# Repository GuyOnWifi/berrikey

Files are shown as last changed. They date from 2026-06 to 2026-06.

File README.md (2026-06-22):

<p align="center">
  
</p>

<h1 align="center">BerriKey</h1>

**A strawberry-themed, hardware key backed by a tamper-proof Secure Element. Built on top of the FIDO2 protocol. Simply plug it in to any site or app that supports the protocol and register a secure authenticator**

## Features

- **nRF52840** microcontroller
- **SE050**, EAL 6+ certified, tamper proof secure element storage for key storage and cryptography
- **USB-C and USB-A** connectivity
- **Capacitive touch pad** for user verification
- **Strawberry shaped case**

## Why?

I wanted to make an actually secure, open source hardware key that I could use for my accounts. Current options like [Yubikeys](https://www.yubico.com/products/) were great but not open-sourced, and community projects like [PicoKey](https://www.picokeys.com/) did not use tamper-resistant storages, and relied on a [chip with known vulnerabilites to it's security features](https://www.raspberrypi.com/news/security-through-transparency-rp2350-hacking-challenge-results-are-in/). I wanted to make it uniquely mine, so I made it strawberry themed!

### Threat model

The purpose of the project was to create a secure key to protected online identity (avoiding use of passwords, which can be keylogged, over-the-shoulder'ed, or leaked)

The main goals were to address the following:

- adversaries: should defend against well funded actors with lab equipment and knowledge (not state actors with supreme funding), evil maid attacks (semi-brief physical attacks)
- attack surface: all crypto operations are performed on SE, only USB (no nfc / ble).
- trust boundaries: SE is ultimate crypto trust, with all operations on the chip. firmware is trusted out of necessity

Most importantly, keys should never be cloneable off device, which would lead to compromise of online identity without knowledge. This mitigates the biggest risk of stealing the key, where the user is expected to assume that it is lost forever and immediately revoke the keys.

## Credits

Credit goes to the [Nitrokey Team](https://github.com/Nitrokey/nitrokey-3-firmware) for creating open-source keys, which this firmware is based on. Rather then reinviting a FIDO2 stack, I forked it off the battle-tested Nitrokey3 that has undergone security audits - ensuring its security against my threat model. It has been modified to support both a USB-C and USB-A, add support to custom LEDs, capacitive touch pads and easier support for programming with the nRF52840 chip. GHowever, the hardware is custom, with a unique form factor.

## Design

### Wiring

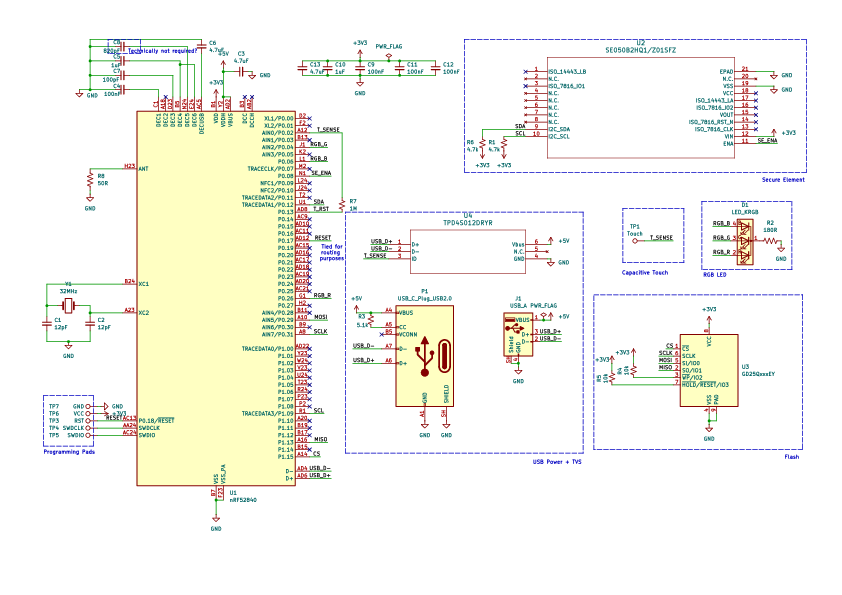
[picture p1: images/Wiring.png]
Wiring


### PCB

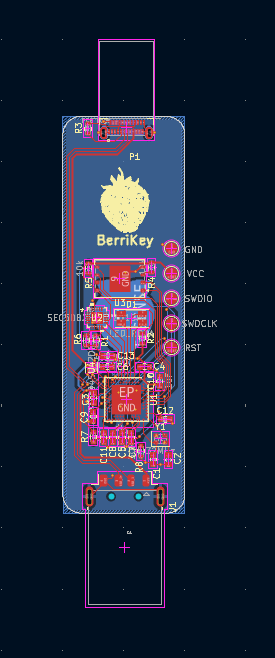
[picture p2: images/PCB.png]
PCB


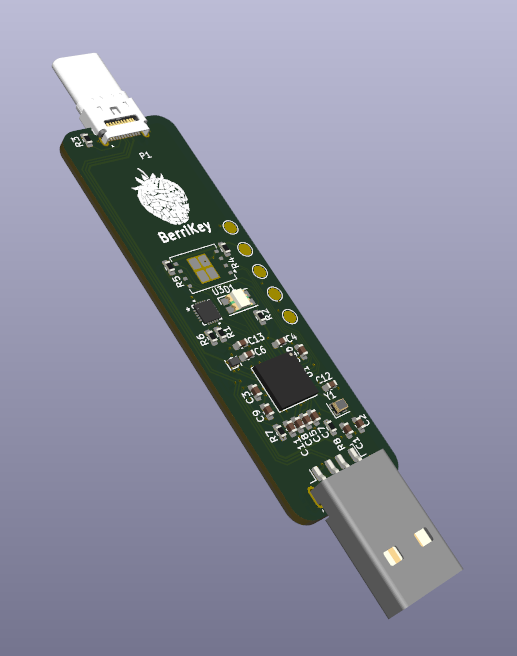
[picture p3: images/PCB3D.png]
PCB-3D


### Case

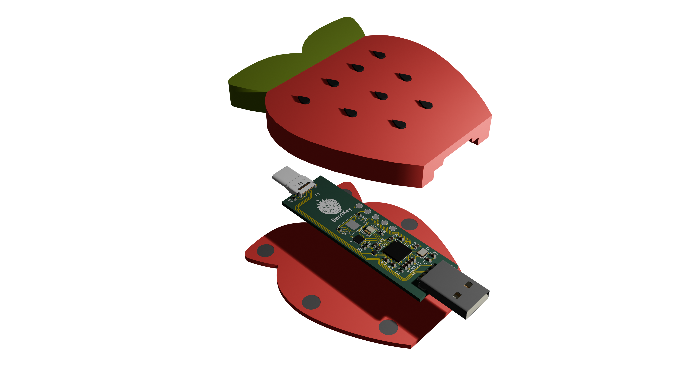
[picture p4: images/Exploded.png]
Exploded view


## Building & Running

5 SWD pads have been exposed on the PCB. Wire them to a CMSIS-DAP debugger (I tested using the RPI debuprobe). Go into `firmware/utils/nrf-builder` and run `make full-deploy`. This will flash the bootloader, provision the keys and certificates, and then flash the firmware.

## Zine

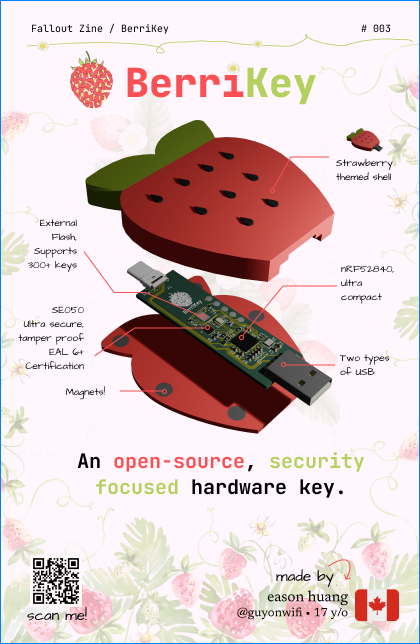
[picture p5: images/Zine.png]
Zine


Check it out [here](./zine.pdf)!

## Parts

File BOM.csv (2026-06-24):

Id | Designator | Footprint | Quantity | Designation | JLCPCB | JLCPCB Link | Price (JLC) | Other Links (unused for JLCPCB assembly, but in case you wanted to build yourself)
1 | C1, C2 | C_0603_1608Metric | 2 | 12pF | Basic Auto Match | N/A | $0.01 | https://www.digikey.ca/en/products/detail/yageo/CC0603JRNPO9BN120/302793
2 | C3, C6, C13 | C_0603_1608Metric | 3 | 4.7uF | Basic Auto Match | N/A | $0.01 | https://www.digikey.ca/en/products/detail/yageo/CC0603KRX5R7BB475/5195193
3 | C4, C9, C11, C12 | C_0603_1608Metric | 4 | 100nF | Basic Auto Match | N/A | $0.01 | https://www.digikey.ca/en/products/detail/yageo/CC0603KRX7R9BB104/2103082
4 | C5, C10 | C_0603_1608Metric | 2 | 1uF | Basic Auto Match | N/A | $0.01 | https://www.digikey.ca/en/products/detail/yageo/CC0603KRX5R9BB105/5195195
5 | C7 | C_0603_1608Metric | 1 | 100pF | Basic Auto Match | N/A | $0.01 | https://www.digikey.ca/en/products/detail/yageo/CC0603JRNPO9BN101/302803
6 | C8 | C_0603_1608Metric | 1 | 820pF | Basic Auto Match | N/A | $0.01 | https://www.digikey.ca/en/products/detail/yageo/CC0603JRNPO9BN821/5195184
7 | D1 | LED_RGB_1210 | 1 | LED_KRGB | FM-B2020RGBA-HG | https://jlcpcb.com/partdetail/110013-FM_B2020RGBAHG/C108793 | $0.02 | https://www.lcsc.com/product-detail/C108793.html
8 | J1 | USB_A_Molex_48037-2200_Horizontal | 1 | USB_A | 48037-2200 | https://jlcpcb.com/partdetail/MOLEX-480372200/C2765195 | $1.01 | https://www.digikey.ca/en/products/detail/molex/0480372200/2421361
9 | P1 | GCT_USB4155-03-C_REVA | 1 | USB_C_Plug_USB2.0 | USB4155-03-C | https://jlcpcb.com/partdetail/5847867-USB4155_03C/C5183853 | $2.22 | https://www.digikey.ca/en/products/detail/gct/USB4155-03-C/14305161
10 | R1, R6 | R_0603_1608Metric | 2 | 4.7k | Basic Auto Match | N/A | $0.01 | https://www.digikey.ca/en/products/detail/yageo/RC0603FR-074K7L/727212
11 | R2 | R_0603_1608Metric | 1 | 180R | Basic Auto Match | N/A | $0.01 | https://www.digikey.ca/en/products/detail/yageo/RC0603FR-07180RL/726994
12 | R3 | R_0603_1608Metric | 1 | 5.1k | Basic Auto Match | N/A | $0.01 | https://www.digikey.ca/en/products/detail/yageo/RC0603FR-075K1L/727268
13 | R4, R5 | R_0603_1608Metric | 2 | 10k | Basic Auto Match | N/A | $0.01 | https://www.digikey.ca/en/products/detail/yageo/RC0603FR-0710KL/726880
14 | R7 | R_0603_1608Metric | 1 | 1M | Basic Auto Match | N/A | $0.01 | https://www.digikey.ca/en/products/detail/yageo/RC0603FR-071ML/726844
15 | R8 | R_0603_1608Metric | 1 | 50R | Basic Auto Match | N/A | $0.01 | https://www.digikey.ca/en/products/detail/yageo/RC0603FR-0749R9L/730211
16 | TP1 | Strawberry_Cap_Touch | 1 | Touch | N/A | N/A | N/A | N/A
17 | TP3 | TestPoint_Pad_D2.0mm | 1 | RST | N/A | N/A | N/A | N/A
18 | TP4 | TestPoint_Pad_D2.0mm | 1 | SWDCLK | N/A | N/A | N/A | N/A
19 | TP5 | TestPoint_Pad_D2.0mm | 1 | SWDIO | N/A | N/A | N/A | N/A
20 | TP6 | TestPoint_Pad_D2.0mm | 1 | VCC | N/A | N/A | N/A | N/A
21 | TP7 | TestPoint_Pad_D2.0mm | 1 | GND | N/A | N/A | N/A | N/A
22 | U1 | Nordic_AQFN-73-1EP_7x7mm_P0.5mm | 1 | nRF52840 | NRF52840-QIAA-R | https://jlcpcb.com/partdetail/NordicSemicon-NRF52840_QIAAR/C190794 | $5.73 | https://www.digikey.ca/en/products/detail/nordic-semiconductor-asa/NRF52840-QIAA-R/7725407
23 | U2 | QFN20_SE050_NXP | 1 | SE050B2HQ1/Z01SFZ | SE050C1HQ1/Z01SCZ | https://jlcpcb.com/partdetail/NXPSemicon-SE050C1HQ1Z01SCZ/C2650415 | $6.17 | https://www.digikey.ca/en/products/detail/nxp-usa-inc/SE050C1HQ1-Z01SCZ/10271723
24 | U3 | WSON-8-1EP_8x6mm_P1.27mm_EP3.4x4.3mm | 1 | GD25QxxxEY | GD25Q16CSIGR | https://jlcpcb.com/partdetail/376201-GD25Q16CSIGR/C395505 | $1.09 | https://www.digikey.ca/en/products/detail/gigadevice-semiconductor-hk-limited/GD25Q16CSIGR/9484689
25 | U4 | DRY6 | 1 | TPD4S012DRYR | TPD4S012DRYR | https://jlcpcb.com/partdetail/TexasInstruments-TPD4S012DRYR/C96506 | $0.43 | https://www.digikey.ca/en/products/detail/texas-instruments/TPD4S012DRYR/2037539
26 | Y1 | Crystal_SMD_3225-4Pin_3.2x2.5mm | 1 | 32MHz | Q22FA12800025 | https://jlcpcb.com/partdetail/SeikoEpson-Q22FA12800025/C187794 | $0.23 | https://www.digikey.ca/en/products/detail/txc-corporation/7V-32-000MAAE-T/2626986
27 | Magnets | 6mmx2mm | 12 | N/A | N/A | N/A | $2.20 | https://www.amazon.ca/GOOZADA-Refrigerator-Magnets-Neodymium-Whiteboards/dp/B0F66HG8RN
Total |  |  |  |  |  |  | $19.22

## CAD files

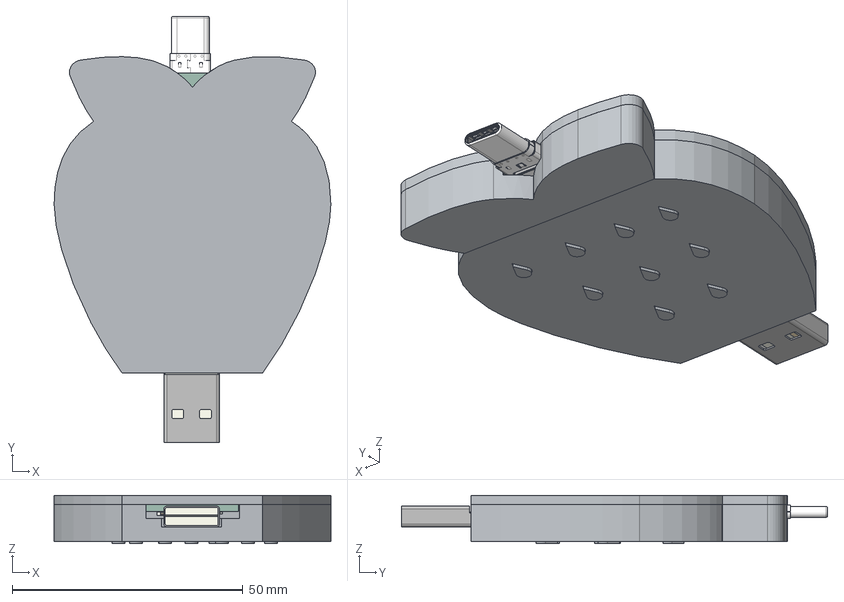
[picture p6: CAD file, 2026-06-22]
3d-models/BerriKey.step
60.0 x 92.3 x 10.5 mm
C_0603_1608Metric
C_0603_1608Metric002
Nordic_AQFN-73-1EP_7x7mm_P0.5mm
R_0603_1608Metric
C_0603_1608Metric004
Ã_Â_Ã_Â¤Ã_Â_Ã_Â«1
Ã_Â_Ã_Â¤Ã_Â_Ã_Â«001
Ã_Â_Ã_Â¤Ã_Â_Ã_Â«002
Ã_Â_Ã_Â¤Ã_Â_Ã_Â«003
Ã_Â_Ã_Â¤Ã_Â_Ã_Â«004
Ã_Â_Ã_Â¤Ã_Â_Ã_Â«005
Ã_Â_Ã_Â¤Ã_Â_Ã_Â«006
Ã_Â_Ã_Â¤Ã_Â_Ã_Â«007
Ã_Â_Ã_Â¤Ã_Â_Ã_Â«008
Ã_Â_Ã_Â¤Ã_Â_Ã_Â«009
Ã_Â_Ã_Â¤Ã_Â_Ã_Â«010
Ã_Â_Ã_Â¤Ã_Â_Ã_Â«011
Ã_Â_Ã_Â¤Ã_Â_Ã_Â«012
Ã_Â_Ã_Â¤Ã_Â_Ã_Â«013
Ã_Â_Ã_Â¤Ã_Â_Ã_Â«014
Ã_Â_Ã_Â¤Ã_Â_Ã_Â«015
Ã_Â_Ã_Â¤Ã_Â_Ã_Â«016
Ã_Â_Ã_Â¤Ã_Â_Ã_Â«017
Ã_Â_Ã_Â¤Ã_Â_Ã_Â«018
Ã_Â_Ã_Â¤Ã_Â_Ã_Â«019
Ã_Â_Ã_Â¤Ã_Â_Ã_Â«020
Ã_Â_Ã_Â¤Ã_Â_Ã_Â«021
Ã_Â_Ã_Â¤Ã_Â_Ã_Â«022
Ã_Â_Ã_Â¤Ã_Â_Ã_Â«023
Ã_Â_Ã_Â¤Ã_Â_Ã_Â«024
Ã_Â_Ã_Â¤Ã_Â_Ã_Â«025
Ã_Â_Ã_Â¤Ã_Â_Ã_Â«026
Ã_Â_Ã_Â¤Ã_Â_Ã_Â«027
Ã_Â_Ã_Â¤Ã_Â_Ã_Â«028
Ã_Â_Ã_Â¤Ã_Â_Ã_Â«029
Ã_Â_Ã_Â¤Ã_Â_Ã_Â«030
Ã_Â_Ã_Â¤Ã_Â_Ã_Â«031
Ã_Â_Ã_Â¤Ã_Â_Ã_Â«032
Ã_Â_Ã_Â¤Ã_Â_Ã_Â«033
Ã_Â_Ã_Â¤Ã_Â_Ã_Â«034
Ã_Â_Ã_Â¤Ã_Â_Ã_Â«035
Ã_Â_Ã_Â¤Ã_Â_Ã_Â«036
Ã_Â_Ã_Â¤Ã_Â_Ã_Â«037
Ã_Â_Ã_Â¤Ã_Â_Ã_Â«038
Ã_Â_Ã_Â¤Ã_Â_Ã_Â«039
Ã_Â_Ã_Â¤Ã_Â_Ã_Â«040
Ã_Â_Ã_Â¤Ã_Â_Ã_Â«041
Ã_Â_Ã_Â¤Ã_Â_Ã_Â«042
Ã_Â_Ã_Â¤Ã_Â_Ã_Â«043
Ã_Â_Ã_Â¤Ã_Â_Ã_Â«044
Ã_Â_Ã_Â¤Ã_Â_Ã_Â«045
Ã_Â_Ã_Â¤Ã_Â_Ã_Â«046
Ã_Â_Ã_Â¤Ã_Â_Ã_Â«047
Ã_Â_Ã_Â¤Ã_Â_Ã_Â«048
Ã_Â_Ã_Â¤Ã_Â_Ã_Â«049
Ã_Â_Ã_Â¤Ã_Â_Ã_Â«050
Ã_Â_Ã_Â¤Ã_Â_Ã_Â«051
Ã_Â_Ã_Â¤Ã_Â_Ã_Â«052
Ã_Â_Ã_Â¤Ã_Â_Ã_Â«053
Ã_Â_Ã_Â¤Ã_Â_Ã_Â«054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

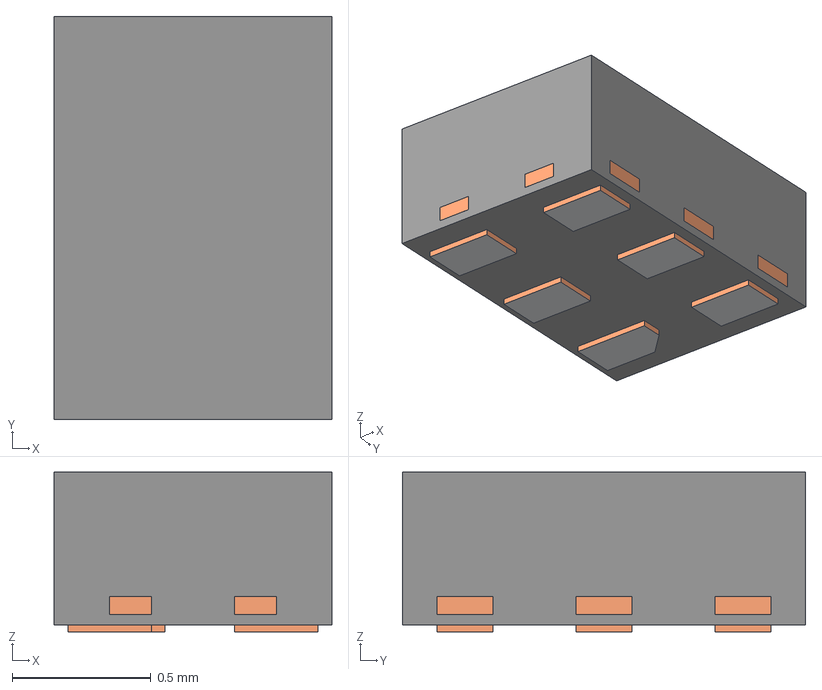
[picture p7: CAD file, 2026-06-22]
kicad/Models/DRY0006A.stp
1.00 x 1.45 x 0.575 mm
BODY-SON
FRAME-DRY0006A
PIN1-ID

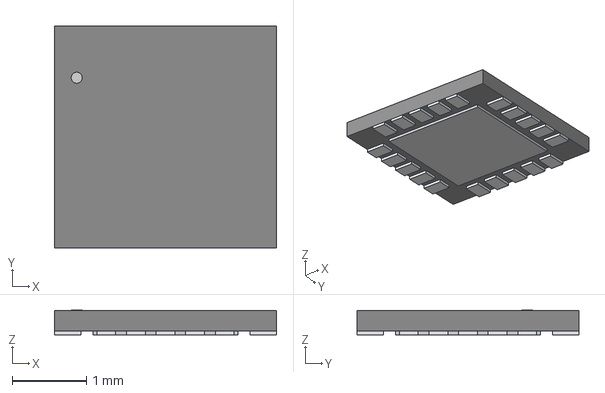
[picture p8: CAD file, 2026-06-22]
kicad/Models/QFN20_SE050_NXP.step
3.00 x 3.00 x 0.333 mm

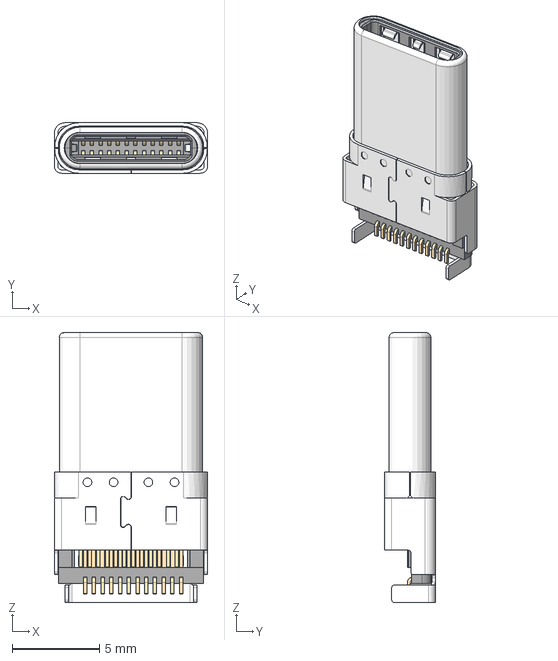
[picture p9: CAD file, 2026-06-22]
kicad/Models/USB4155-03.STEP
8.80 x 2.90 x 15.5 mm
ÊäÈë1 x 7
ÇÐ³ý-ÀÉì2

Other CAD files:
3d-models/BerriKey.FCStd
3d-models/BerriKey.blend

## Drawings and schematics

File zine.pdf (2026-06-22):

# BerriKey

# 003

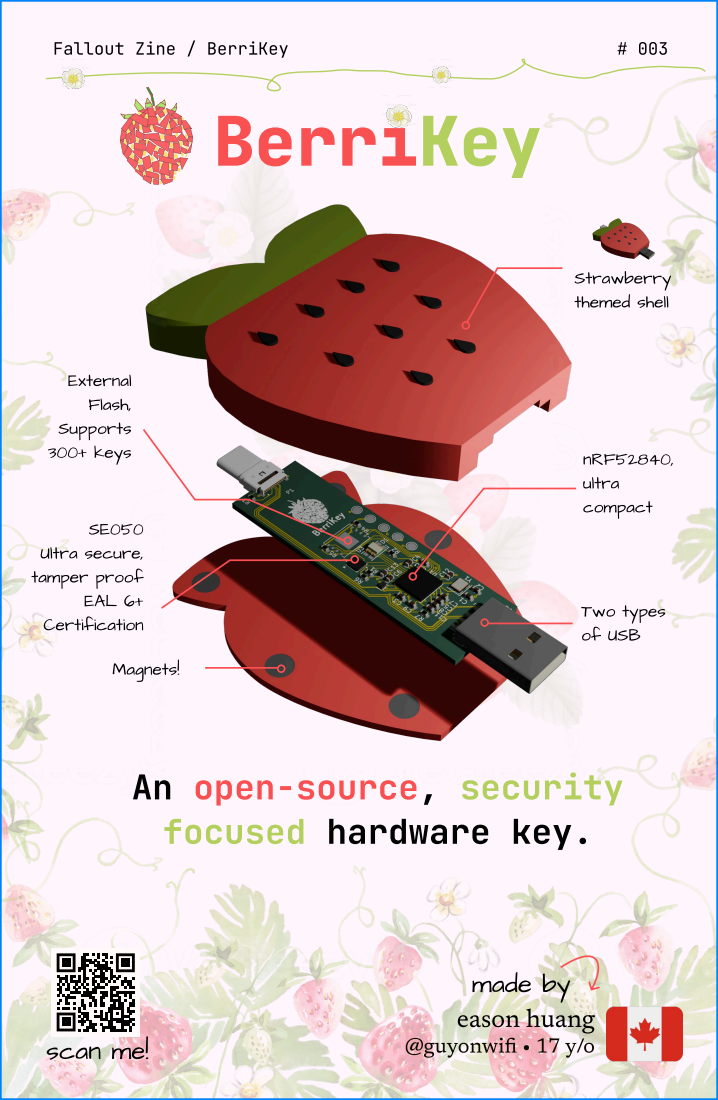
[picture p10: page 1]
Strawberry; themed shell; External; Flash,; Supports; 300+ keys; Ultra secure,; tamper proof; EAL 6+; Certification; Magnets!; nRF52840,; ultra; compact; Two types; of USB; scan me!; made by

Fallout Zine / BerriKey

An open-source, security

focused hardware key.

eason huang @guyonwifi • 17 y/o

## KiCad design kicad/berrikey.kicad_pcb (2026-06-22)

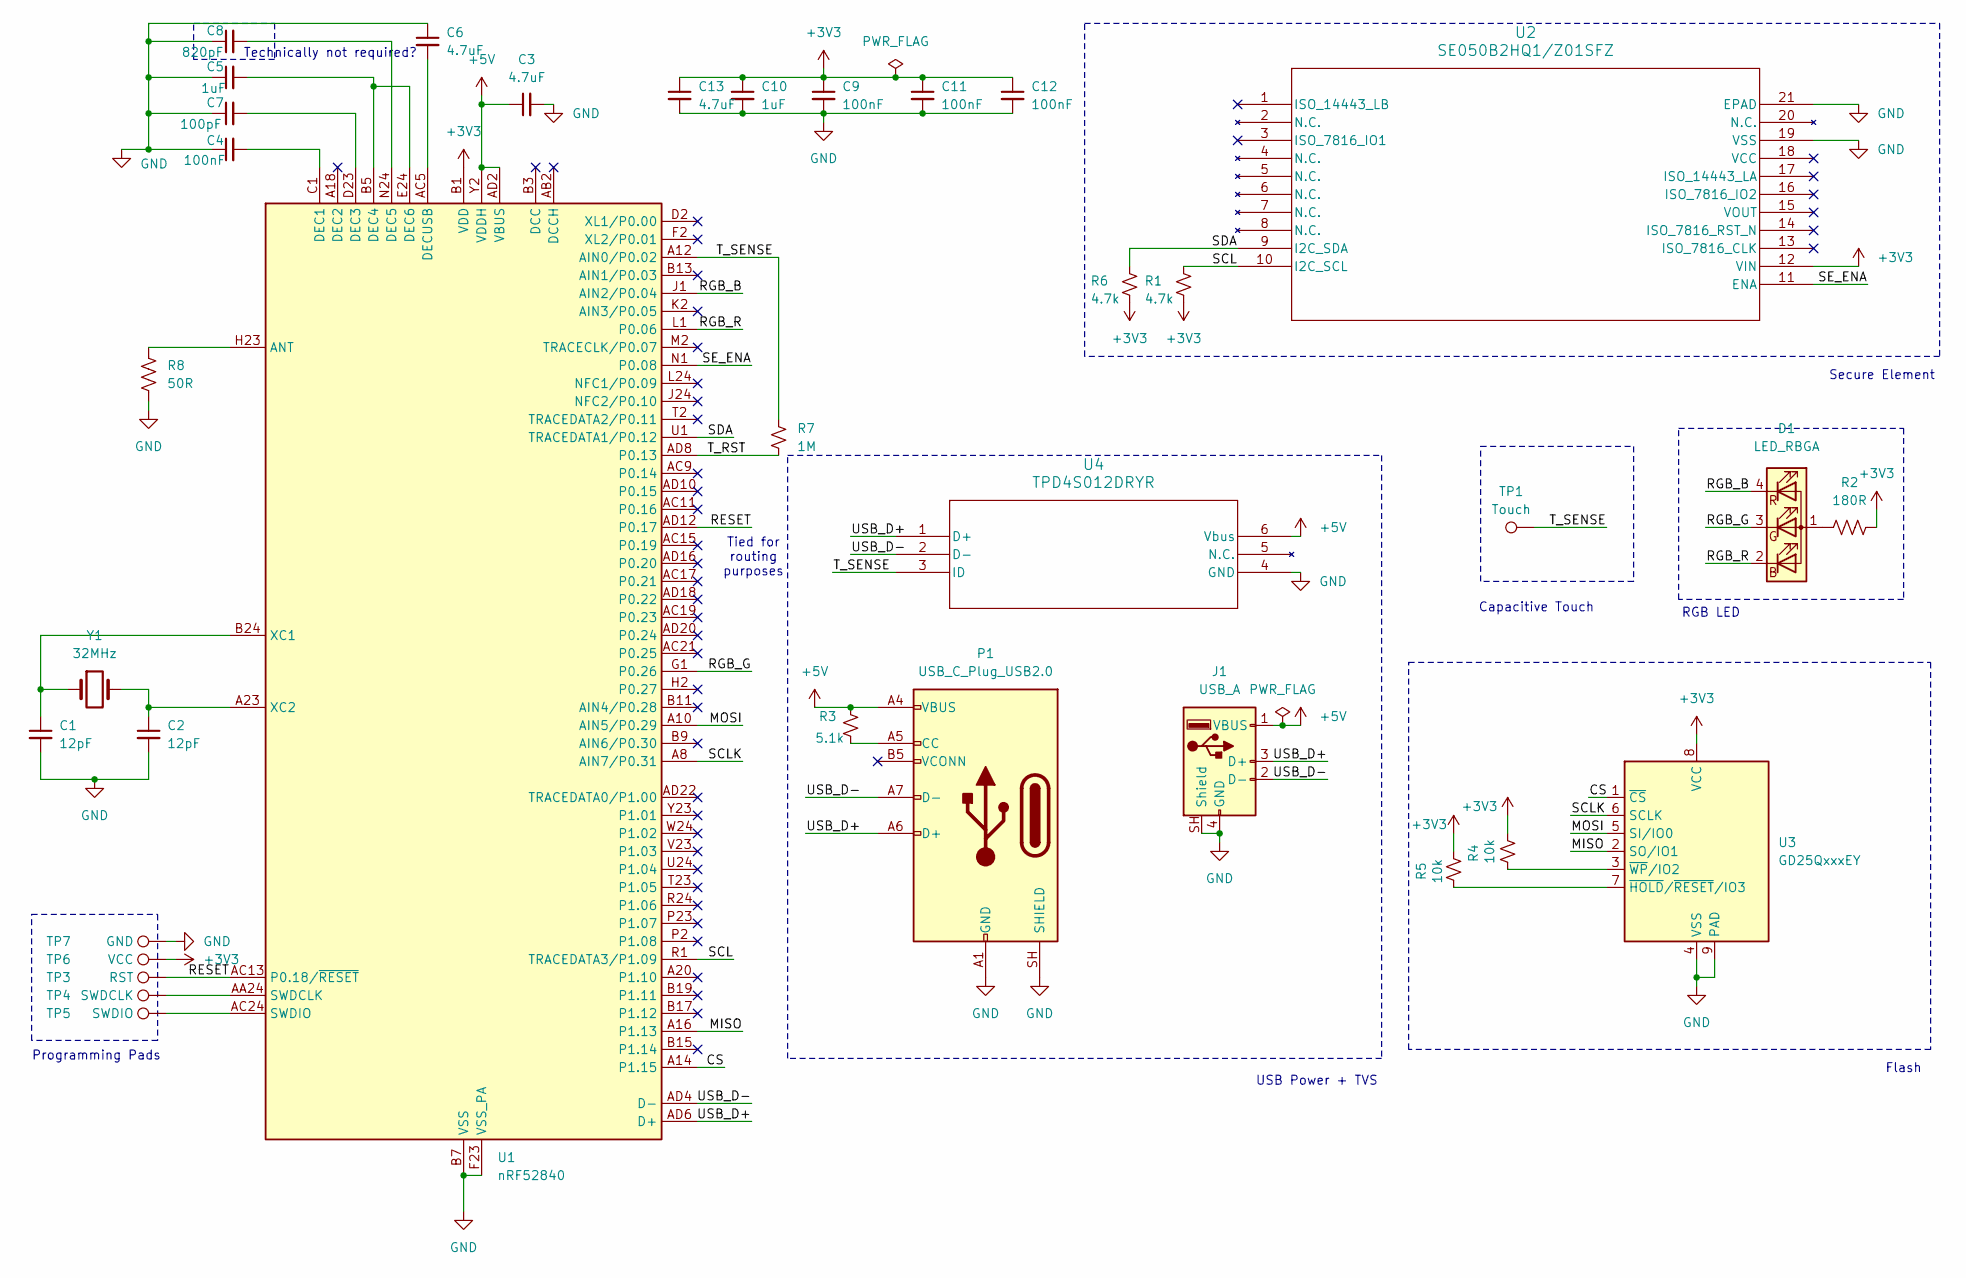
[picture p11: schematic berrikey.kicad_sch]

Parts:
C1, C2: 12pF; C_0603_1608Metric
C3, C6, C13: 4.7uF; C_0603_1608Metric
C4, C9, C11, C12: 100nF; C_0603_1608Metric
C5, C10: 1uF; C_0603_1608Metric
C7: 100pF; C_0603_1608Metric
C8: 820pF; C_0603_1608Metric
D1: LED_RBGA; LED_RGB_1210
J1: USB_A; USB_A_Molex_48037-2200_Horizontal
P1: USB_C_Plug_USB2.0; GCT_USB4155-03-C_REVA
R1, R6: 4.7k; R_0603_1608Metric
R2: 180R; R_0603_1608Metric
R3: 5.1k; R_0603_1608Metric
R4, R5: 10k; R_0603_1608Metric
R7: 1M; R_0603_1608Metric
R8: 50R; R_0603_1608Metric
TP1: Touch; Strawberry_Cap_Touch
TP3: RST; TestPoint_Pad_D2.0mm
TP4: SWDCLK; TestPoint_Pad_D2.0mm
TP5: SWDIO; TestPoint_Pad_D2.0mm
TP6: VCC; TestPoint_Pad_D2.0mm
TP7: GND; TestPoint_Pad_D2.0mm
U1: nRF52840; Nordic_AQFN-73-1EP_7x7mm_P0.5mm
U2: SE050B2HQ1/Z01SFZ; QFN20_SE050_NXP
U3: GD25QxxxEY; WSON-8-1EP_8x6mm_P1.27mm_EP3.4x4.3mm
U4: TPD4S012DRYR; DRY6
Y1: 32MHz; Crystal_SMD_2016-4Pin_2.0x1.6mm

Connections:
+3V3: C9.1, C10.1, C11.1, C12.1, C13.1, R1.2, R2.2, R4.1, R5.1, R6.2, TP6.1 (1_1), U1.A22 (VDD), U1.AD14 (VDD), U1.AD23 (VDD), U1.B1 (VDD), U1.W1 (VDD), U2.12 (VIN), U3.8 (VCC)
+5V: C3.1, J1.1 (VBUS), P1.A4 (VBUS), P1.A9 (VBUS), P1.B4 (VBUS), P1.B9 (VBUS), R3.1, U1.AD2 (VBUS), U1.Y2 (VDDH), U4.6 (Vbus)
/CS: U1.A14 (P1.15), U3.1 (~CS)
/MISO: U1.A16 (P1.13), U3.2 (SO/IO1)
/MOSI: U1.A10 (AIN5/P0.29), U3.5 (SI/IO0)
/RESET: TP3.1 (1_1), U1.AC13 (P0.18/~RESET), U1.AD12 (P0.17)
/RGB_B: D1.4 (RK), U1.J1 (AIN2/P0.04)
/RGB_G: D1.3 (GK), U1.G1 (P0.26)
/RGB_R: D1.2 (BK), U1.L1 (P0.06)
/SCL: R1.1, U1.R1 (TRACEDATA3/P1.09), U2.10 (I2C_SCL)
/SCLK: U1.A8 (AIN7/P0.31), U3.6 (SCLK)
/SDA: R6.1, U1.U1 (TRACEDATA1/P0.12), U2.9 (I2C_SDA)
/SE_ENA: U1.N1 (P0.08), U2.11 (ENA)
/T_RST: R7.2, U1.AD8 (P0.13)
/T_SENSE: R7.1, TP1.1 (1_1), U1.A12 (AIN0/P0.02), U4.3 (ID)
/USB_D+: J1.3 (D+), P1.A6 (D+), U1.AD6 (D+), U4.1 (D+)
/USB_D-: J1.2 (D-), P1.A7 (D-), U1.AD4 (D-), U4.2 (D-)
GND: C1.2, C2.2, C3.2, C4.1, C5.1, C6.1, C7.1, C8.1, C9.2, C10.2, C11.2, C12.2, C13.2, J1.4 (GND), J1.SH (Shield), P1.A1 (GND), P1.A12 (GND), P1.B1 (GND), P1.B12 (GND), P1.S1, P1.S2, P1.SH (SHIELD), R8.2, TP7.1 (1_1), U1.B7 (VSS), U1.EP (VSS), U1.F23 (VSS_PA), U2.19 (VSS), U2.21 (EPAD), U3.4 (VSS), U3.9 (PAD), U4.4 (GND), Y1.2, Y1.4
unnamed: D1.1 (A), R2.1
unnamed: P1.A5 (CC), R3.2
unnamed: R8.1, U1.H23 (ANT)
unnamed: C4.2, U1.C1 (DEC1)
unnamed: C7.2, U1.D23 (DEC3)
unnamed: C5.2, U1.B5 (DEC4), U1.E24 (DEC6)
unnamed: C8.2, U1.N24 (DEC5)
unnamed: C6.2, U1.AC5 (DECUSB)
unnamed: TP4.1 (1_1), U1.AA24 (SWDCLK)
unnamed: TP5.1 (1_1), U1.AC24 (SWDIO)
unnamed: C1.1, U1.B24 (XC1), Y1.1
unnamed: C2.1, U1.A23 (XC2), Y1.3
unnamed: R5.2, U3.7 (~HOLD/~RESET/IO3)
unnamed: R4.2, U3.3 (~WP/IO2)

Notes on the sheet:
RGB LED
Flash
Programming Pads
USB Power + TVS
Tied for routing purposes
Secure Element
Technically not required?
Capacitive Touch

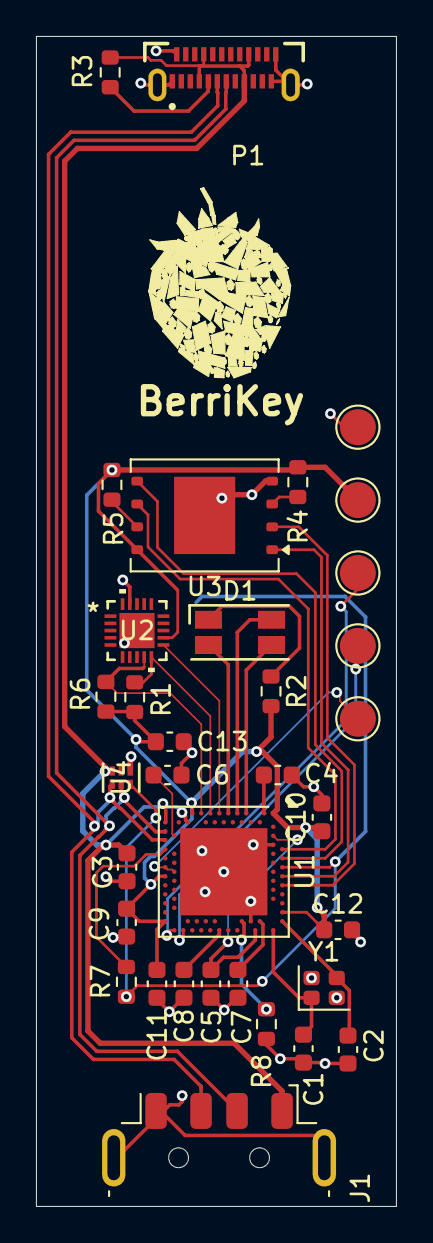
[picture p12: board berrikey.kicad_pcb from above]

Board: 2 copper layers, 20.0 x 65.0 mm, 35 parts (1 on the bottom side), 32 nets.

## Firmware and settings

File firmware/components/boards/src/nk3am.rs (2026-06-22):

use littlefs2::{
    fs::{Allocation, Filesystem},
    io::Result as LfsResult,
};
use memory_regions::MemoryRegions;
use nfc_device::traits::nfc::{Device as NfcDevice, Error as NfcError, State as NfcState};
use nrf52840_hal::{
    gpio::{p0, p1, Level, Output, Pin, PushPull},
    gpiote::Gpiote,
    spim, twim, Spim,
};
use nrf52840_pac::{FICR, GPIOTE, P0, P1, POWER, PWM0, PWM1, PWM2, SPIM3};

#[cfg(feature = "se050")]
use {
    nrf52840_hal::{prelude::OutputPin as _, timer::Timer, Twim},
    nrf52840_pac::{TIMER1, TWIM1},
    se05x::embedded_hal::Hal027,
};

use crate::{
    flash::ExtFlashStorage,
    soc::nrf52::{flash::FlashStorage, rtic_monotonic::RtcMonotonic, Nrf52, UsbClockType},
    ui::UserInterface,
    Board,
};

use migrations::ftl_journal::{self, ifs_flash_old::FlashStorage as OldFlashStorage};
use ui::{HardwareButtons, RgbLed};

pub mod ui;

mod migrations;

type OutPin = Pin<Output<PushPull>>;

const MEMORY_REGIONS: &MemoryRegions = &MemoryRegions::NK3AM;

pub struct NK3AM;

impl Board for NK3AM {
    type Soc = Nrf52;

    type Resources = UsbClockType;

    type NfcDevice = DummyNfc;
    type Buttons = HardwareButtons;
    type Led = RgbLed;

    type InternalStorage = InternalFlashStorage;
    type ExternalStorage = ExternalFlashStorage;

    #[cfg(feature = "se050")]
    type Twi = Hal027<Twim<TWIM1>>;
    #[cfg(feature = "se050")]
    type Se050Timer = Hal027<Timer<TIMER1>>;
    #[cfg(not(feature = "se050"))]
    type Twi = ();
    #[cfg(not(feature = "se050"))]
    type Se050Timer = ();

    const BOARD_NAME: &'static str = "NK3AM";
    const HAS_NFC: bool = false;

    fn prepare_ifs(ifs: &mut Self::InternalStorage) {
        ifs.format_journal_blocks();
    }

    fn recover_ifs(
        ifs_storage: &mut Self::InternalStorage,
        ifs_alloc: &mut Allocation<Self::InternalStorage>,
        efs_storage: &mut Self::ExternalStorage,
    ) -> LfsResult<()> {
        error_now!("IFS (nrf42) mount-fail");

        // regular mount failed, try mounting "old" (pre-journaling) IFS
        let pac = unsafe { nrf52840_pac::Peripherals::steal() };
        let mut old_ifs_storage = OldFlashStorage::new(pac.NVMC);
        let mut old_ifs_alloc: Allocation<OldFlashStorage> = Filesystem::allocate();
        let old_mountable = Filesystem::is_mountable(&mut old_ifs_storage);

        // we can mount the old ifs filesystem, thus we need to migrate
        if old_mountable {
            let mounted_ifs = ftl_journal::migrate(
                &mut old_ifs_storage,
                &mut old_ifs_alloc,
                ifs_alloc,
                ifs_storage,
                efs_storage,
            );
            // migration went fine => use its resulting IFS
            if let Ok(()) = mounted_ifs {
                info_now!("migration ok, mounting IFS");
                Ok(())
            // migration failed => format IFS
            } else {
                error_now!("failed migration, formatting IFS");
                Filesystem::format(ifs_storage)
            }
        } else {
            info_now!("recovering from journal");
            // IFS and old-IFS cannot be mounted, try to recover from journal
            ifs_storage.recover_from_journal();
            Ok(())
        }
    }
}

pub type InternalFlashStorage =
    FlashStorage<{ MEMORY_REGIONS.filesystem.start }, { MEMORY_REGIONS.filesystem.end }>;
pub type ExternalFlashStorage = ExtFlashStorage<Spim<SPIM3>, OutPin>;

pub struct DummyNfc;

impl NfcDevice for DummyNfc {
    fn read(&mut self, _buf: &mut [u8]) -> Result<NfcState, NfcError> {
        Err(NfcError::NoActivity)
    }
    fn send(&mut self, _buf: &[u8]) -> Result<(), NfcError> {
        Err(NfcError::NoActivity)
    }
    fn frame_size(&self) -> usize {
        0
    }
}

pub struct BoardGPIO {
    pub gpiote: Gpiote,

    /* interactive elements */
    pub rgb_led: [OutPin; 3],
    pub touch: OutPin,

    /* Secure Element (through TWIM1) */
    pub se_pins: Option<twim::Pins>,
    pub se_power: Option<OutPin>,

    /* External Flash & NFC (through SxPIM3) */
    pub flashnfc_spi: Option<spim::Pins>,
    pub flash_cs: Option<OutPin>,
}

pub fn init_pins(gpiote: GPIOTE, p0: P0, p1: P1) -> BoardGPIO {
    let gpiote = Gpiote::new(gpiote);
    let gpio_p0 = p0::Parts::new(p0);
    let gpio_p1 = p1::Parts::new(p1);

    /* touch sensor */
    let touch = gpio_p0.p0_02.into_push_pull_output(Level::High).degrade();
    // not used, just ensure output + low
    gpio_p0.p0_13.into_push_pull_output(Level::Low).degrade();

    /* RGB LED */
    let led_r = gpio_p0.p0_06.into_push_pull_output(Level::Low).degrade();
    let led_g = gpio_p0.p0_26.into_push_pull_output(Level::Low).degrade();
    let led_b = gpio_p0.p0_04.into_push_pull_output(Level::Low).degrade();

    /* SE050 */
    let se_pwr = gpio_p0.p0_08.into_push_pull_output(Level::Low).degrade();
    let se_scl = gpio_p1.p1_09.into_floating_input().degrade();
    let se_sda = gpio_p0.p0_12.into_floating_input().degrade();

    let se_pins = twim::Pins {
        scl: se_scl,
        sda: se_sda,
    };

    /* Ext. Flash SPI */
    // Flash WP# gpio_p0.p0_22
    // Flash HOLD# gpio_p0.p0_23
    let flash_spi_cs = gpio_p1.p1_15.into_push_pull_output(Level::High).degrade();
    let flash_spi_clk = gpio_p0.p0_31.into_push_pull_output(Level::Low).degrade();
    let flash_spi_mosi = gpio_p0.p0_29.into_push_pull_output(Level::Low).degrade();
    let flash_spi_miso = gpio_p1.p1_13.into_floating_input().degrade();
    //let _flash_wp = gpio_p0.p0_22.into_push_pull_output(Level::Low).degrade();
    //let _flash_hold = gpio_p0.p0_23.into_push_pull_output(Level::High).degrade();

    let flash_spi = spim::Pins {
        sck: flash_spi_clk,
        miso: Some(flash_spi_miso),
        mosi: Some(flash_spi_mosi),
    };

    gpiote.reset_events();

    BoardGPIO {
        gpiote,
        rgb_led: [led_r, led_g, led_b],
        touch,
        se_pins: Some(se_pins),
        se_power: Some(se_pwr),
        flashnfc_spi: Some(flash_spi),
        flash_cs: Some(flash_spi_cs),
    }
}

pub fn init_ui(
    leds: [OutPin; 3],
    pwm_red: PWM0,
    pwm_green: PWM1,
    pwm_blue: PWM2,
    touch: OutPin,
) -> UserInterface<RtcMonotonic, HardwareButtons, RgbLed> {
    // TODO: safely share the RTC
    let pac = unsafe { nrf52840_pac::Peripherals::steal() };
    let rtc_mono = RtcMonotonic::new(pac.RTC0);

    let rgb = RgbLed::new(leds, pwm_red, pwm_green, pwm_blue);
    let buttons = HardwareButtons::new(touch);

    UserInterface::new(rtc_mono, Some(buttons), Some(rgb))
}

pub fn init_external_flash(spim3: SPIM3, spi: spim::Pins, cs: OutPin) -> ExternalFlashStorage {
    let spim = Spim::new(spim3, spi, spim::Frequency::M2, spim::MODE_0, 0x00u8);
    ExtFlashStorage::try_new(spim, cs).unwrap()
}
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

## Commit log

2026-06-20 WHOOO PROJECT
    [BOM.csv, BerriKey.FCStd, BerriKey.blend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]
2026-06-20 add pricing
    [BOM.csv]
2026-06-22 Add 3d models, update README and pin mappings!
    [DRY0006A.stp, QFN20_SE050_NXP.step, USB4155-03.STEP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]
2026-06-22 updated 3d models!
    [BerriKey.FCStd, BerriKey.step]
2026-06-24 add magnets to BOM
    [BOM.csv]

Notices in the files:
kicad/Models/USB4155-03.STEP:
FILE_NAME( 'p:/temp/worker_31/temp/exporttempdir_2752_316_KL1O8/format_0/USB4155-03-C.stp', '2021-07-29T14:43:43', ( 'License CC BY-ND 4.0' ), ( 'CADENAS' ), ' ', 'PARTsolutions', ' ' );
